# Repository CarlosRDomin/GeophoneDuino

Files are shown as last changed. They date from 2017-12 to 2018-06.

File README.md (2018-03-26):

# GeophoneDuino
This repository contains everything related to our Arduino ESP8266 based Geophone sensing node (although it could be used to sample any other sensor).

<table><tr style="border: 0;">
<td width="150" style="border: 0;">
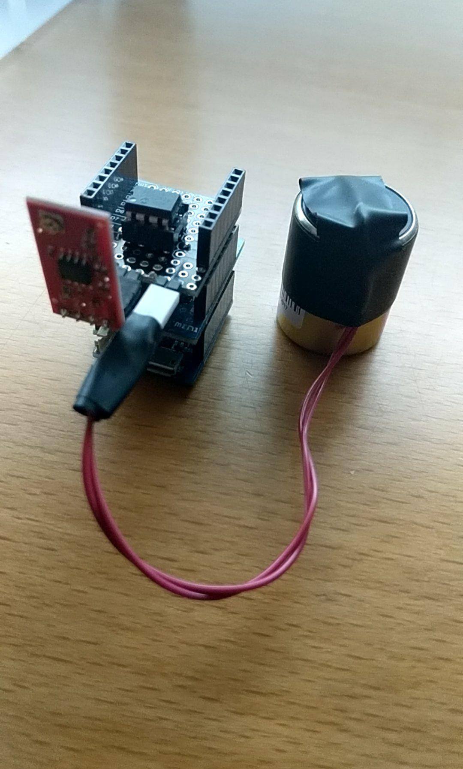
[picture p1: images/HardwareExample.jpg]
Sample GeophoneDuino sensing node
  
</td><td style="border: 0;">
  <h2>Hardware</h2>
  The code assumes the following hardware components are stacked on top of each other:
  <ul>
    <li>Our custom protoshield with an MCP3201 (SPI 12bit ADC), an _optional_ opamp to amplify the geophone signal and the geophone sensor</li>
    <li>WeMos D1 mini (the Arduino ESP8266 itself)</li>
    <li>(_Optional_) Battery shield</li>
  </ul>
</td>
</tr></table>

## Instructions

### Cloning the repo
For the scripts to work, it is important to **clone** the repo instead of simply downloading it.
  1. Locate your Arduino home folder (usually under `<home_dir>/Documents/Arduino` or `<home_dir>/Arduino`)
  2. Open a terminal and navigate to that folder. _E.g._ `cd ~/Documents/Arduino`
  3. Clone the repo:
    ```sh
    git clone https://github.com/CarlosRDomin/GeophoneDuino.git
    ```

### Installing 3rd-party libraries
In order to make it easier to install all libraries, plugins and the Esp8266 core, I added a Python script called `setup.py` (which uses `git submodule` to fetch the right version of each library). To make it easier to read the output of the script, it uses the `coloredlogs` library so messages are color-coded (there should be no red messages unless something went wrong ;P). The steps are:
  1. Open a Terminal console and install the helper Python libraries:
    ```sh
    pip install coloredlogs verboselogs
    ```
  2. Navigate to the root folder in this repo (_e.g._ `cd ~/Documents/Arduino/GeophoneDuino`)
  3. Execute the installation script:
     ```sh
     python setup.py -i
     ```
  **NOTE**: this would install the libraries and the board into the **default Arduino folder** (_eg_ for Mac: `~/Documents/Arduino`). If your `Arduino` folder is somewhere else, specify such path as an argument to the Python script like this: `python setup.py -i -p <PATH>`

  **NOTE 2**: If you get an error like `IOError: [Errno socket error] [SSL: TLSV1_ALERT_PROTOCOL_VERSION] tlsv1 alert protocol version (_ssl.c:590)`, follow these steps:
    1. Install Miniconda2:
      1. Download the [installation script](https://repo.continuum.io/miniconda/Miniconda2-latest-MacOSX-x86_64.sh)
	  2. Execute it:
		```sh
		bash Miniconda2-latest-MacOSX-x86_64.sh
		```
	  3. Prepend miniconda to your `PATH` on `~/.bash_profile` by adding the line: `export PATH="$HOME/miniconda2/bin:$PATH"`
	  4. Reopen the terminal (or open a new tab) so changes take place (_e.g._, `which python` should point to `$HOME/miniconda2/bin/python`)
    2. Try installing the 3rd-party libraries again (`python setup.py -i`)

  **NOTE 3**: If you get a message like `No Java runtime present, requesting install`, you need to install the [Java JDK 8](http://www.oracle.com/technetwork/java/javase/downloads/jdk8-downloads-2133151.html). Just download the latest update (`8u162` as of March 2018) and open the installer (takes ~1min)

### Installing the USB drivers
The Arduino ESP8266 uses a CH34x chip instead of the more common FTDI. Therefore, the right drivers need to be installed in order for the board to show up when you plug it in through USB. Driver file (for Mac) is available under `Datasheets and useful info/CH34x_Install_V1.4.pkg`. Simply double click and follow the on-screen instructions (might need to reboot).

### How to flash the firmware?
 1. Open the file `GeophoneDuino.ino` in the Arduino IDE.
 2. Plug in the ESP8266 through USB, select the right port on `Tools > Port` (_eg_: `\dev\cu.wchusbserial14440`) and configure the board as:
   - Board: WeMos D1 R2 & mini
   - Flash size: 4M (1M SPIFFS)
   - Debug port: Disabled
   - Debug level: None
   - lwIP variant: v2 higher bandwidth
   - CPU frequency: 160 MHz
   - Upload speed: 921600
   - Erase Flash: only Sketch
 3. Copy SPIFFS (filesystem) files by clicking on `Tools > ESP8266 upload SPIFFS files`. This step will allow you to:
       - Connect to the Arduino's own hotspot (which is automatically created whenever it is unable to connect to the default WiFi network), perform a network scan and [configure which network it should connect to](#how-to-configure-which-network-to-join).
       - [Visualize sensor data in real-time wirelessly](#how-to-see-real-time-sensor-data) (doesn't even need an Internet connection)
 4. Upload the sketch (`Sketch > Upload`)

### How to configure which network to join?
In order to wirelessly interact with the Arduino, both devices need to be in the same network. One could change these settings in the code and reflash the firmware every time the testing/deployment environment changes, but sometimes this isn't ideal.

Instead, the Arduino will create its own hotspot if it is unable to connect to the preconfigured network within 10s, so that we can connect to it and update its settings.
Note that by default, the network name will be `Geophone_ABCDEF` (where `ABCDEF` will be replaced by its hex serial number) and password will be `geophone`.

Once connected, its IP should be `192.168.0.1`. We can access its wireless settings by opening a web browser and navigating to `192.168.0.1/WiFi`. The webpage will automatically trigger a network scan and all available networks will be displayed within a few seconds. Then, we can configure which network to join, the password, desired IP, etc. and click Connect.
Note that, upon successful network connection, the hotspot will be turned off and therefore our laptop/device will also need to connect to a different network.

### How to see real-time sensor data?
Once both the Arduino and our laptop/phone/device are connected to the same network, we can simply open a web browser and navigate to `<Arduino IP>/` or, equivalently, `<Arduino IP>/index.html` and a live stream of data will show up. Click `Close socket` to stop streaming or `Save data` to download a `csv` file with all data recorded.

### How to collect (store to file) data?
The Python script to collect data relies on a WebSocket implementation and a colored logging library which need to be installed before the first use. Simply open a terminal and execute:
```sh
pip install ws4py coloredlogs verboselogs
```

Then, you have two options to specify which IP(s) to collect data from:
  * As a list (`-l`, separated by spaces):
    ```sh
    python data_collection.py -l 192.168.0.101 192.168.0.105 192.168.0.109
    ```
  * As a range (`-r`, entering IP prefix, followed by the starting and ending (inclusive) IPs in the range):
    ```sh
    python data_collection.py -r 192.168.0 102 107  # Would connect to 192.168.0.102, 192.168.0.103, ..., 192.168.0.107
    ```

For additional parameters or for help, type `python data_collection.py -h`.
To stop collecting data, press `Ctrl + C` at any time.

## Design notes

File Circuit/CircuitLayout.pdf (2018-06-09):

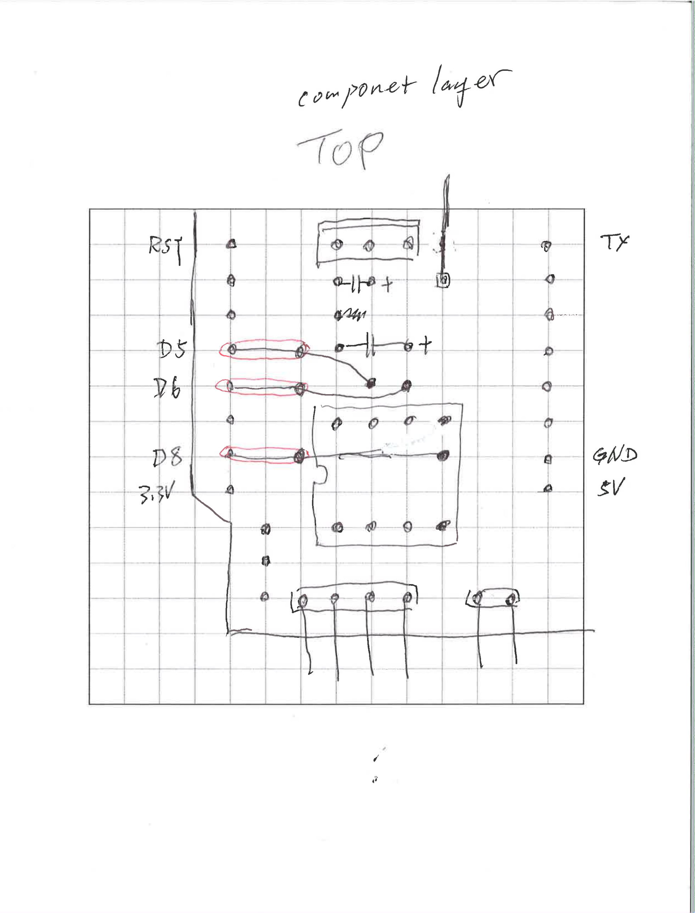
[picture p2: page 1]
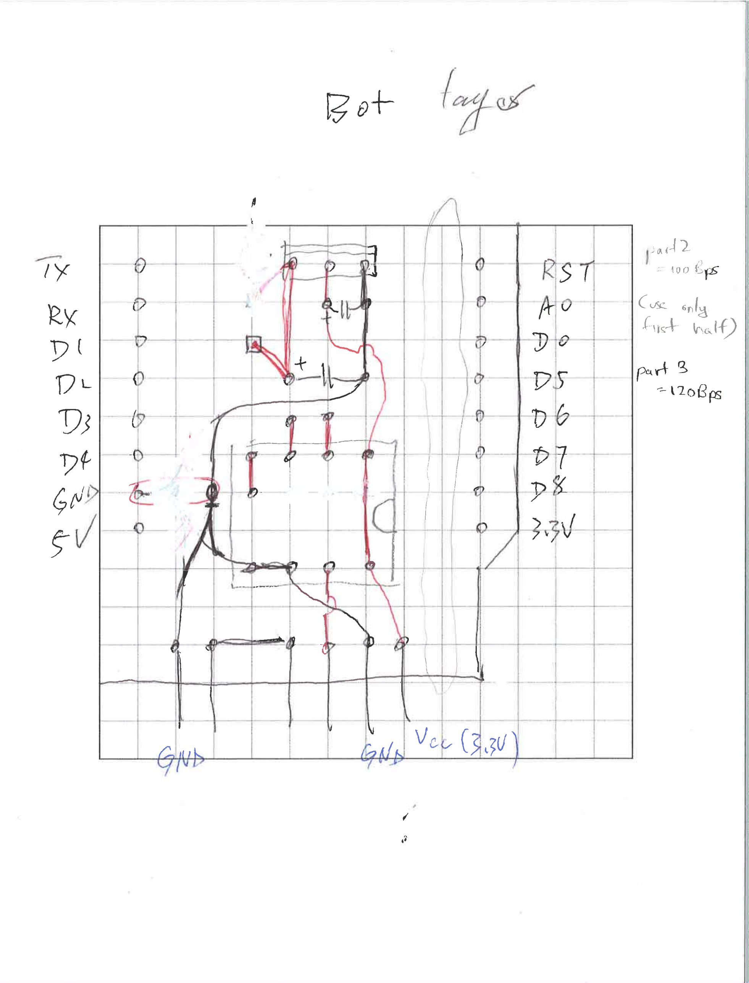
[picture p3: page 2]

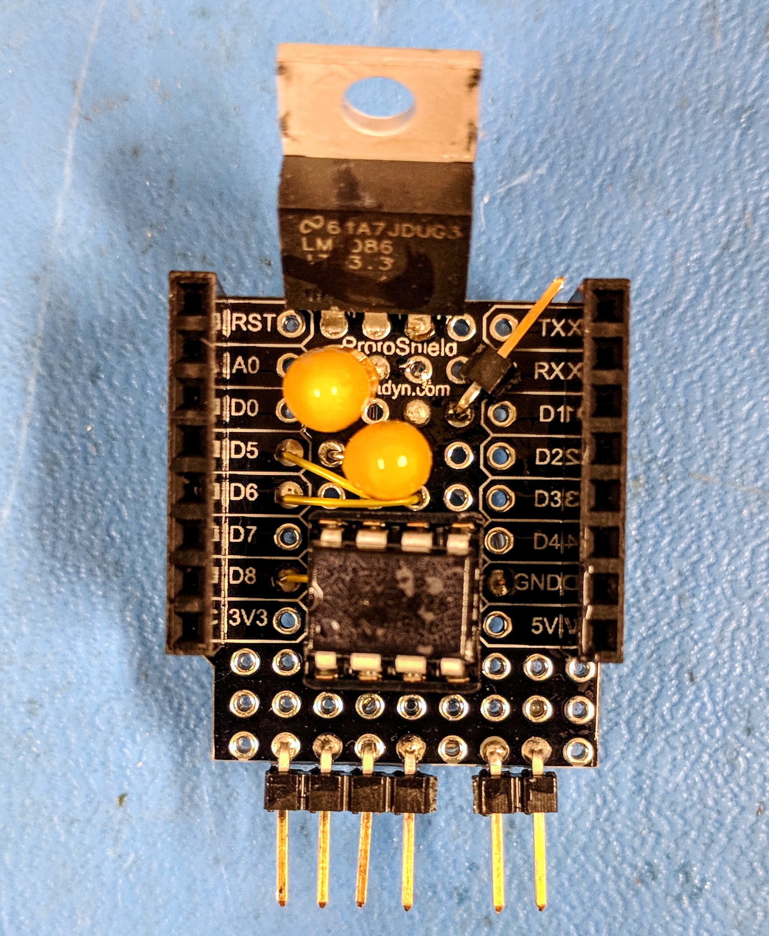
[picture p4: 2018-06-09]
Circuit/TopView.jpg

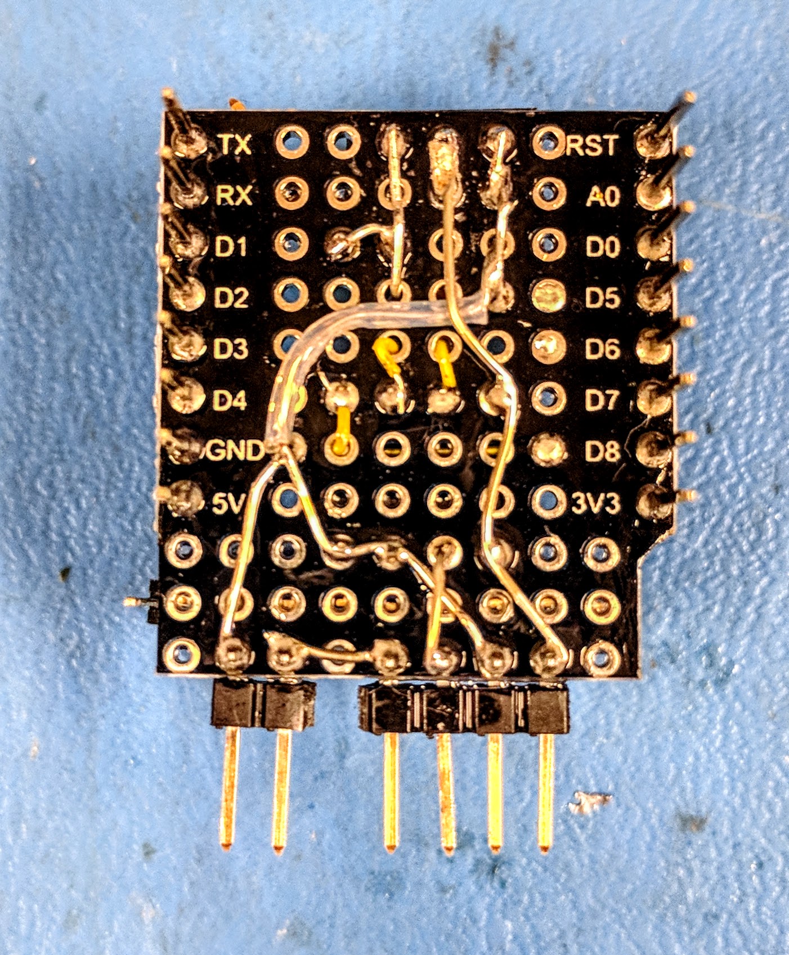
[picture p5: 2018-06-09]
Circuit/BottomView.jpg

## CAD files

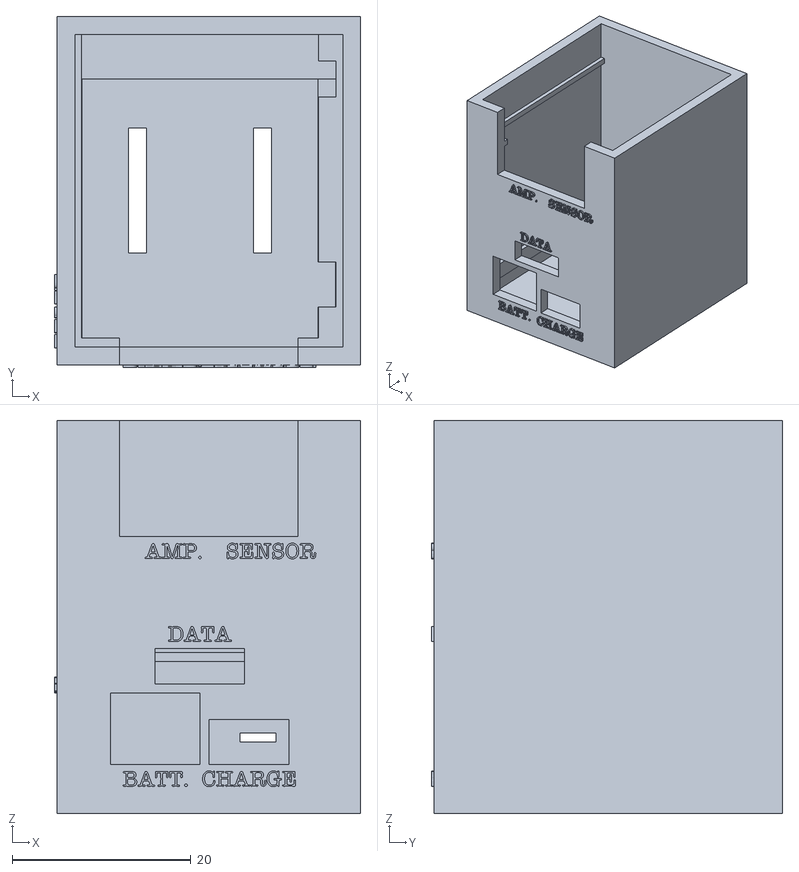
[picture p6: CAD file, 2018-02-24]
3D models/GeophoneDuino case.stl
34.3 x 39.3 x 44.0

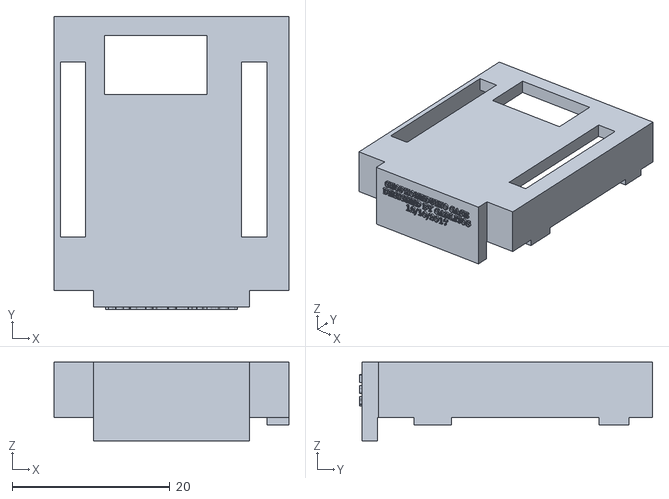
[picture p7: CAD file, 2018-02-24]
3D models/GeophoneDuino case cover.stl
29.8 x 37.2 x 10.0

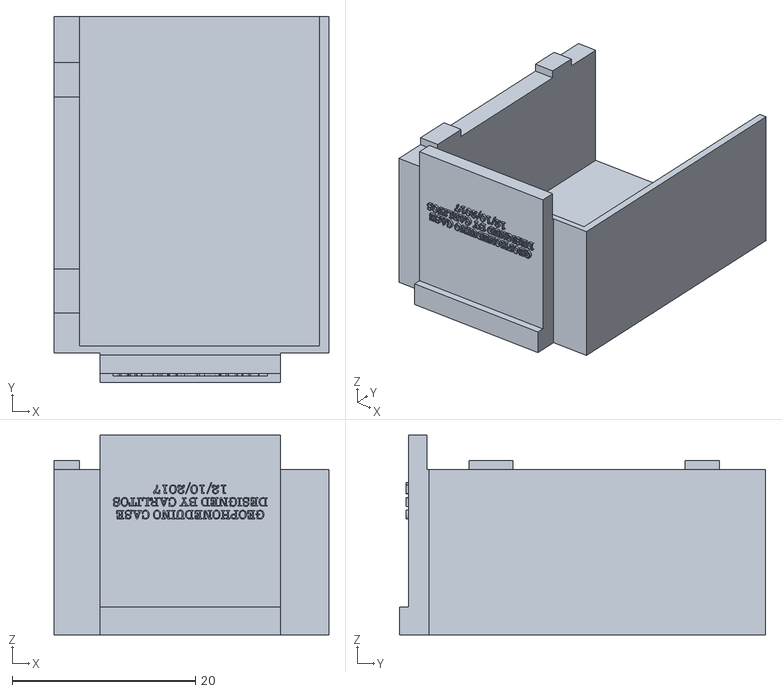
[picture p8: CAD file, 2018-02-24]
3D models/GeophoneDuino case cover Thai.stl
30.0 x 39.9 x 21.8

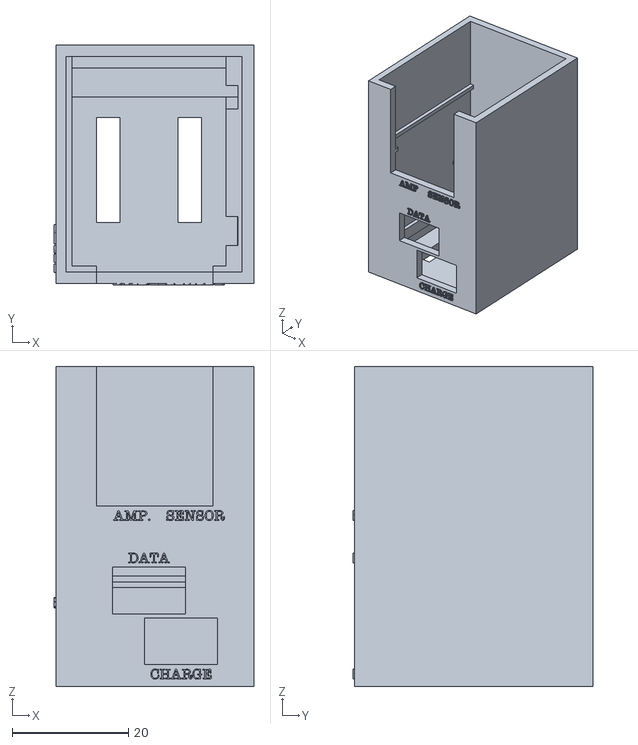
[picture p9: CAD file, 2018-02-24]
3D models/GeophoneDuino case Thai.stl
34.3 x 41.3 x 55.0

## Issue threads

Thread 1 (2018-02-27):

SPIFFS Error: mkspiffs not found!

chenx376, 2018-02-27:
```python
IOError: [Errno socket error] [SSL: TLSV1_ALERT_PROTOCOL_VERSION] tlsv1 alert protocol version (_ssl.c:590)
```
[Solution](https://stackoverflow.com/questions/44316292/ssl-sslerror-tlsv1-alert-protocol-version)

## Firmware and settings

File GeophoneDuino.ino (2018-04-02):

/******      HotTub main file      ******/
#include "main.h"
#include "GPIO.h"
#include "WiFi.h"
#include "webServer.h"

uint32_t curr_time;


/***************************************************/
/******            SETUP FUNCTIONS            ******/
/***************************************************/
void setup() {
	curr_time = millis();
	Serial.begin(115200);
	Serial.setDebugOutput(true);	// Print debug messages through Serial (for debugging)
	while(!Serial);	// Wait for serial port to connect

	setupWiFi();
	setupWebServer();
	setupIOpins();

	delay(1000);
}


/*********************************************/
/******            MAIN LOOP            ******/
/*********************************************/
void loop() {
	curr_time = millis();
	processGPIO();
	processWiFi();
	processWebServer();
	delay(20);
}

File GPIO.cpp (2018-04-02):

/******      GPIO      ******/
#include "GPIO.h"

uint16_t geophone_buf[2][GEOPHONE_BUF_SIZE+1];	// ADC data buffer, double buffered
unsigned int geophone_buf_id_current = 0;	// Which data buffer is being used for the ADC (the other is being sent)
unsigned int geophone_buf_pos = 1;	// Position (index) in the ADC data buffer (start at 1 because [0] keeps track of geophone_buf_num_sent)
uint16_t geophone_buf_num_sent = 0;
bool geophone_buf_got_full = false;	// Flag to signal that a buffer is ready to be sent
bool printGeophoneDebug = false;
bool haveSetTimer1 = false;


/***************************************************/
/******            SETUP FUNCTIONS            ******/
/***************************************************/

void setupIOpins() {	// Setup all IO pins, including on-board pins and MCP23017
	pinMode(LED_BUILTIN, OUTPUT);
	digitalWrite(LED_BUILTIN, LOW);	// Turn on LED to show we're turning on...
	analogWriteRange(PWM_RANGE);	// Set the PWM range (0 to PWM_RANGE) so we can blink "heartbeat" LED
	spiBegin();		// Start SPI (so we can read ADC samples)
	setupTimer1();	// And start the timer to sample ADC
}

void setupTimer1() {
	timer1_isr_init();
	timer1_attachInterrupt(sample_isr);
	timer1_enable(TIM_DIV16, TIM_EDGE, TIM_LOOP);
	timer1_write(clockCyclesPerMicrosecond() / 16 / 2 * 100); //100us = 10kHz sampling freq
}

static inline void setDataBits(uint16_t bits) {
    const uint32_t mask = ~((SPIMMOSI << SPILMOSI) | (SPIMMISO << SPILMISO));
    bits--;
    SPI1U1 = ((SPI1U1 & mask) | ((bits << SPILMOSI) | (bits << SPILMISO)));
}

void spiBegin() {
  SPI.begin();
  SPI.setDataMode(SPI_MODE0);
  SPI.setBitOrder(MSBFIRST);
  SPI.setClockDivider(SPI_CLOCK_DIV8); 
  SPI.setHwCs(1);
  setDataBits(16);
}

/* SPI code based on the SPI library */
static inline ICACHE_RAM_ATTR uint16_t transfer16() {
	union {
		uint16_t val;
		struct {
			uint8_t lsb;
			uint8_t msb;
		};
	} out;


	// Transfer 16 bits at once, leaving HW CS low for the whole 16 bits 
	while(SPI1CMD & SPIBUSY) {}
	SPI1W0 = 0;
	SPI1CMD |= SPIBUSY;
	while(SPI1CMD & SPIBUSY) {}

	/* Follow MCP3201's datasheet: return value looks like this:
	xxxBA987 65432101
	We want 
	76543210 0000BA98
	So swap the bytes, select 12 bits starting at bit 1, and shift right by one.
	*/

	out.val = SPI1W0 & 0xFFFF;
	uint8_t tmp = out.msb;
	out.msb = out.lsb;
	out.lsb = tmp;

	out.val &= (0x0FFF << 1);
	out.val >>= 1;
	return out.val;
}


/**********************************************/
/******      GPIO related functions      ******/
/**********************************************/
void ICACHE_RAM_ATTR sample_isr() {
	// Read a sample from ADC and write it to the buffer
	uint16_t val = transfer16();
	geophone_buf[geophone_buf_id_current][geophone_buf_pos] = val;
	geophone_buf_pos++;

	// If the buffer is full, switch to the other one and signal that it's ready to be sent
	if (geophone_buf_pos > sizeof(geophone_buf[0])/sizeof(geophone_buf[0][0])) {
		//wsGeophone.binaryAll(reinterpret_cast<uint8_t*>(geophone_buf[geophone_buf_id_current]), sizeof(geophone_buf[0]));
		geophone_buf_pos = 1;
		geophone_buf_id_current = !geophone_buf_id_current;
		geophone_buf[geophone_buf_id_current][0] = (++geophone_buf_num_sent);
		geophone_buf_got_full = true;
	}
}

void processGPIO() {	// "GPIO.loop()" function: reads inputs, processes them and writes outputs
	// Blink built-in LED to show we're alive :)
	//analogWrite(LED_BUILTIN, (((curr_time>>10) & 0x01)? curr_time:~curr_time) & 0x3FF);	// Fading heartbeat every ~1s [for binary heartbeat use instead: digitalWrite(LED_BUILTIN, (curr_time>>10) & 0x01);]
	digitalWrite(LED_BUILTIN, (curr_time>>10) & 0x01);	// Analog write uses CPU to fake a PWM -> Because we use high CPU it doesn't work -> Use traditional "binary" toggle
	
	// Read inputs (geophone)
	static uint32_t t_sample = micros();
	if (printGeophoneDebug) {
		consolePrintF("@t=%8d ms -> Latest ADC sample:%4d\n", millis(), geophone_buf[geophone_buf_id_current][geophone_buf_pos]);
	}

	if (!haveSetTimer1) {
		haveSetTimer1 = true;
		setupTimer1();	// For some reason, WiFi or something else resets timer1 settings, so we gotta keep setting it up...
	}
}

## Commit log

2018-02-24 Gzip large web files for smaller SPIFFS footprint
2018-02-24 Move 3D models to their own folder
    [GeophoneDuino case Thai.stl, GeophoneDuino case cover Thai.stl, GeophoneDuino case cover.stl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]
2018-02-24 Update jQuery and Plotly versions on html files and add Refresh button on WiFi scanning webpage
2018-02-24 Temporary fix for bug in ESPAsyncWebServer
    AsyncWebServerRequest::arg(const __FlashStringHelper * data) has a bug (going to submit a pull request later) and breaks, so for now, we manually cast the __FlashStringHelper to String using my SF() macro instead of the F() macro
    [webServer.cpp]
2018-02-28 Update data_collection.py to save into a new file every x seconds
    Now there's one thread per IP to collect data from. In case we got disconnected, the thread will keep retrying to connect
2018-03-06 Ignore Geophone ID message
    Matlab seems to have trouble importing csv files with mixed text and numbers -> Ignore Geophone ID (Geophone_AABBCC) so it's all just 12-bit ADC values
2018-03-06 DataReceiver inherits from Thread besides WebSocketBaseClient
    Simplify websocket client class by having DataReceiver also inherit from thread (now we can call websocket.close() from the the reference to the thread)
2018-03-26 Add helper script to load Plotly and jQuery from the internet, then from the Arduino as a backup
    When connected to the Arduino through its WiFi AP, there's no internet so loading any page (eg: /index.html) freezes for ~20s (attempting to load the CDN copy of Plotly and jQuery) then tries to load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
    Instead, this helper script checks internet connectivity and decides which script to load (CDN vs local) within 2s.
2018-03-26 Update web interface to expect websocket data to be sent as binary instead of plaintext
    Also use WebWorkers so each message is processed in a different thread to prevent blocking the main thread
2018-03-26 Add FFT support (allows to also broadcast FFT of the ADC buffer data through a websocket)
2018-03-26 Add arduinoFFT as a dependency so it gets automatically symlinked
2018-03-26 Add a note to the README in case JDK is not installed
2018-04-02 Send message ID (counter) together with ADC data [changes on Arduino side]
2018-04-02 Send message ID (counter) together with ADC data [changes on Python side]
2018-04-02 Send message ID (counter) together with ADC data [changes on web side]
2018-04-02 Modify compiler flags to define custom macros for ArduinoWebSockets library
2018-06-06 update on circuit
    the circuit layout as well as the photos of the top and bottom view of the ADC board are added
